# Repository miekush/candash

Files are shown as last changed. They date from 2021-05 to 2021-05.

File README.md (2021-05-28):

# CANDash
STM32 based Controller Area Network Dashboard

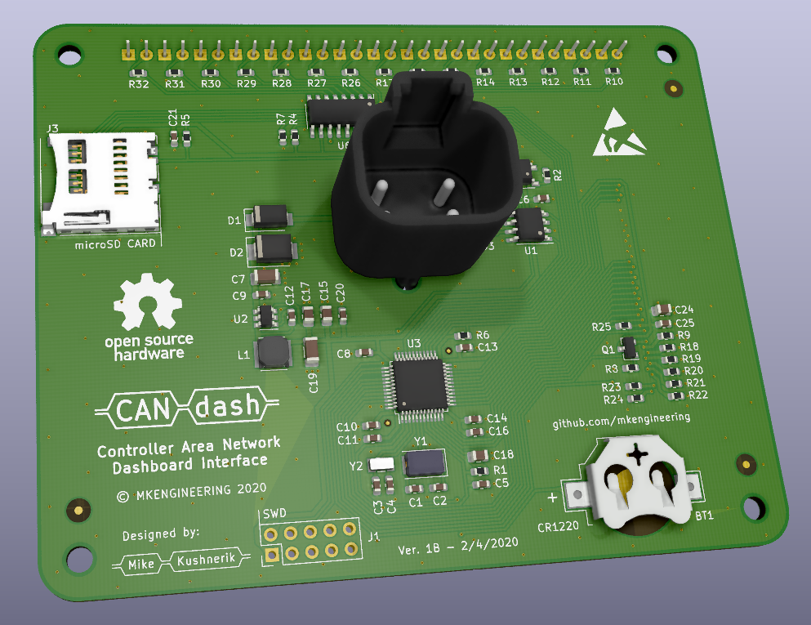
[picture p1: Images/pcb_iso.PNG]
PCB


Designed by Mike Kushnerik (MKE) in KiCad V5

# License

MKE supports the open source hardware community by sharing hardware design files freely on GitHub!

Please support MKE by purchasing products on [Tindie](https://www.tindie.com/stores/mkengineering/)!

Designed by Mike Kushnerik for MKEngineering

Licensed under [Creative Commons Attribution-ShareAlike CC BY-SA 3.0](http://creativecommons.org/licenses/by-sa/3.0/)

All text above must be included in any redistribution!

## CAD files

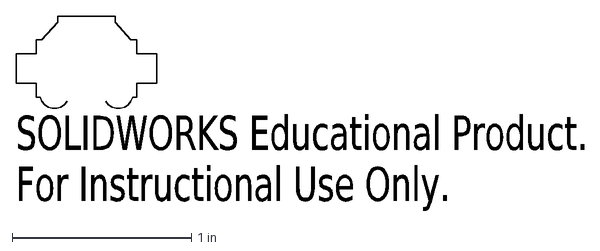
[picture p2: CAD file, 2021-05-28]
3D Models/keystone-PN3000TR_outline.DXF
SOLIDWORKS Educational Product.
For Instructional Use Only.

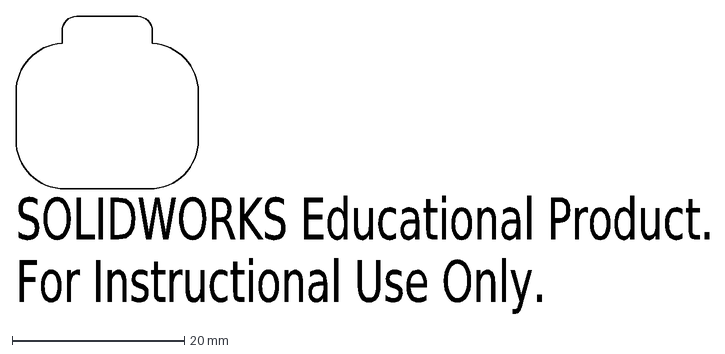
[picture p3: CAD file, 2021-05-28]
3D Models/AT04-4P-BM03_front_porch.DXF
SOLIDWORKS Educational Product.
For Instructional Use Only.

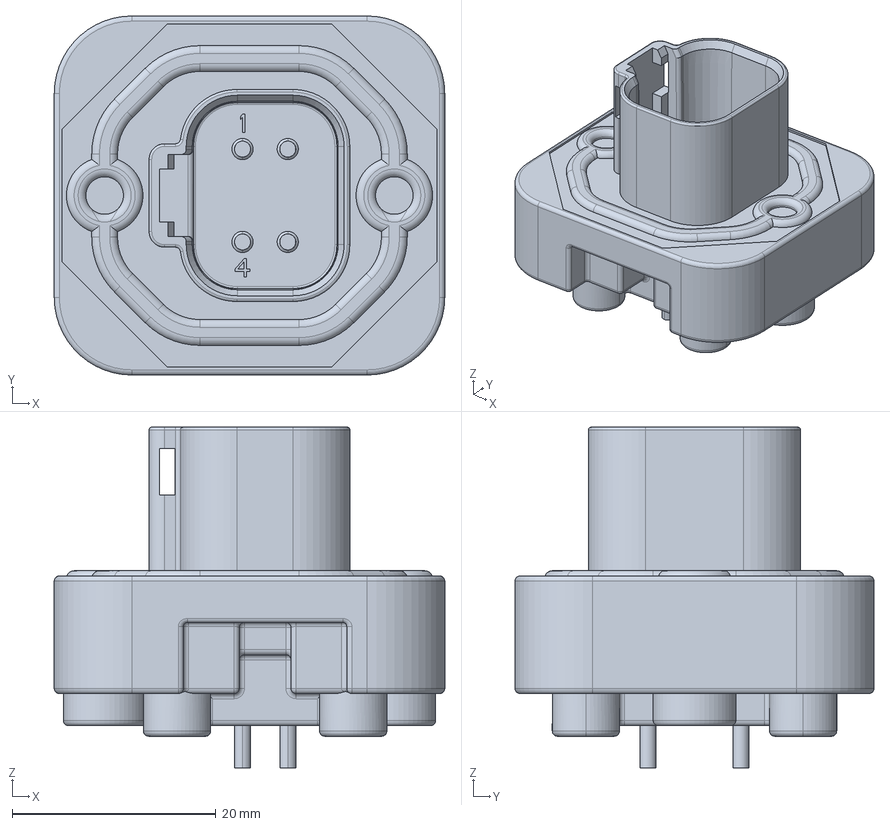
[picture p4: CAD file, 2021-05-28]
3D Models/c-dt15-4p-99-3d.stp
38.4 x 35.3 x 33.5 mm

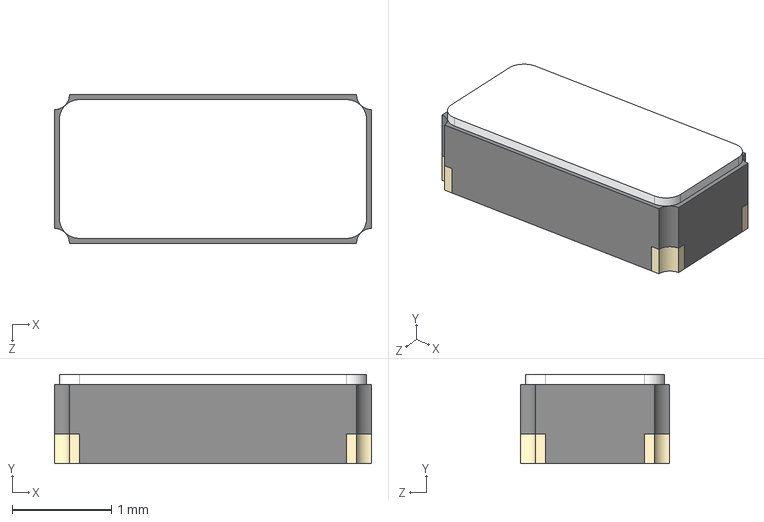
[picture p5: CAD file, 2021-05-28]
3D Models/ABS07-32.768KHZ-1-T.STEP
3.20 x 0.9 x 1.50 mm

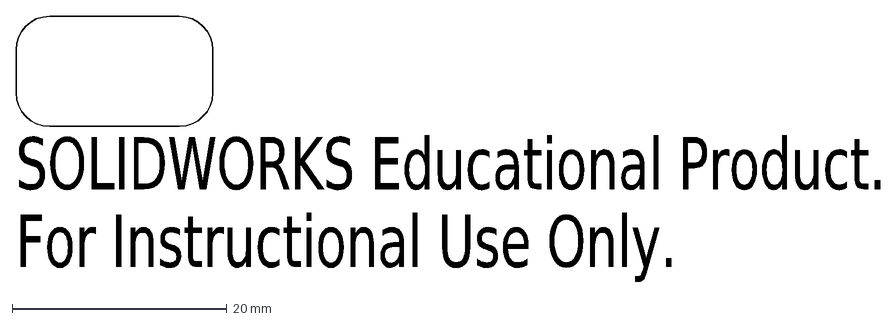
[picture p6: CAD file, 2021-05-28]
3D Models/AT04-4P-BM03_outline.DXF
SOLIDWORKS Educational Product.
For Instructional Use Only.

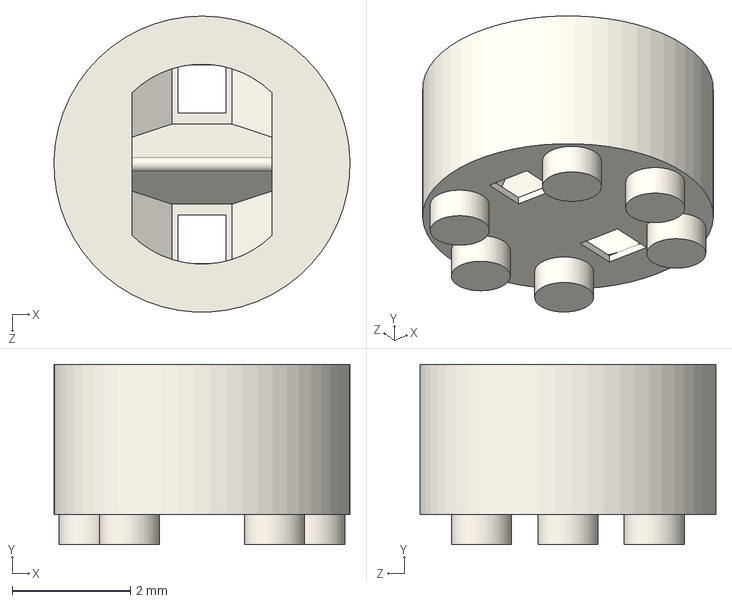
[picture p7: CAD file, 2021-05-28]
3D Models/keystone-PN7351.STEP
5.00 x 3.05 x 5.00 mm

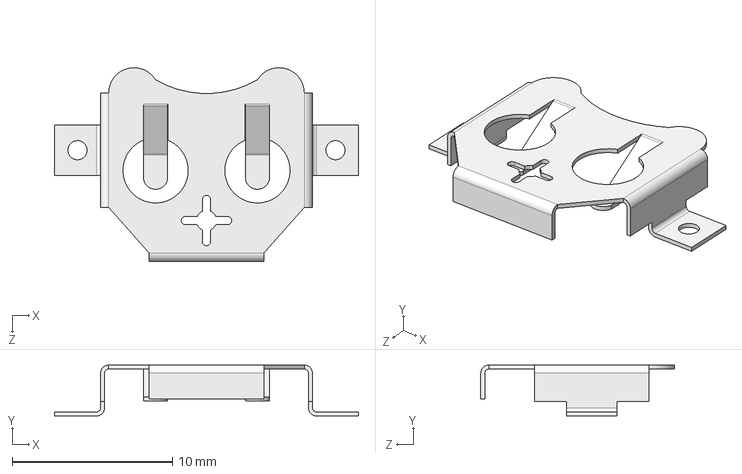
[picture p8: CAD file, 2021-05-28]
3D Models/keystone-PN3000TR.STEP
18.9 x 3.17 x 12.1 mm

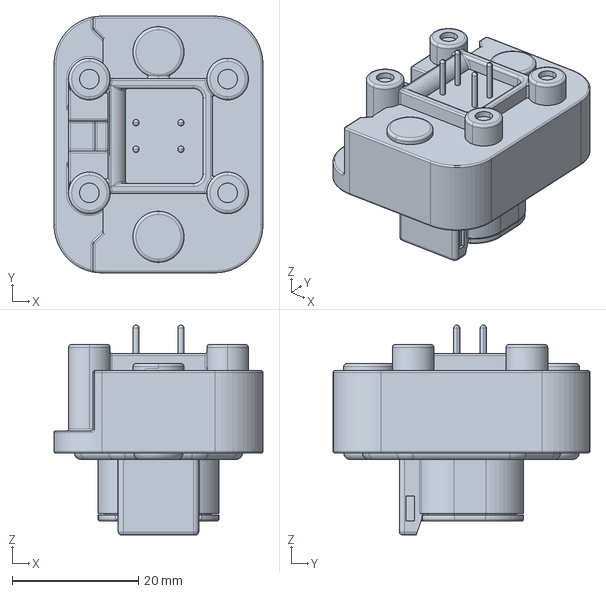
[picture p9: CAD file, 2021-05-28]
3D Models/c-atm15-4p-bm03-3d-c3d.STP
33.1 x 40.7 x 33.2 mm

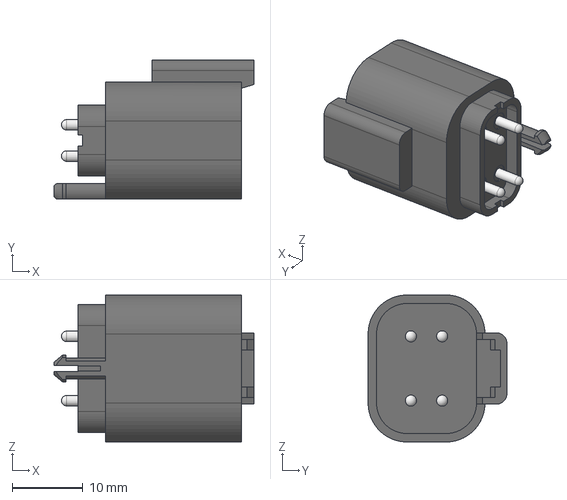
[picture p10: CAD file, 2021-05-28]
3D Models/AT04-4P-BM03.stp
28.3 x 19.6 x 20.8 mm

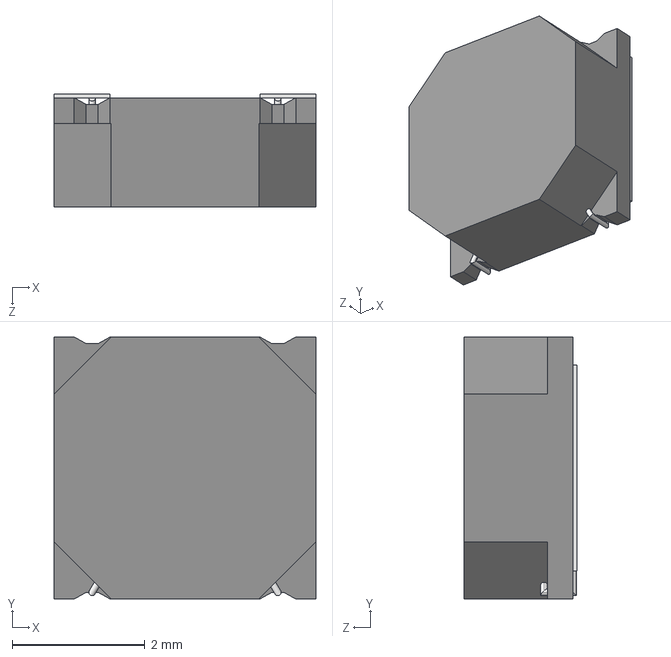
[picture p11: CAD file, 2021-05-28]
3D Models/IFSC1515AHER4R7M01.stp
3.95 x 3.95 x 1.71 mm

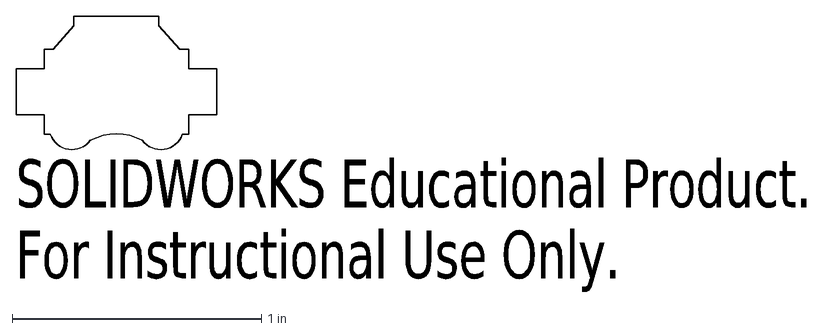
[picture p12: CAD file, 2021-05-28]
3D Models/keystone-PN3000TR_front_porch.DXF
SOLIDWORKS Educational Product.
For Instructional Use Only.

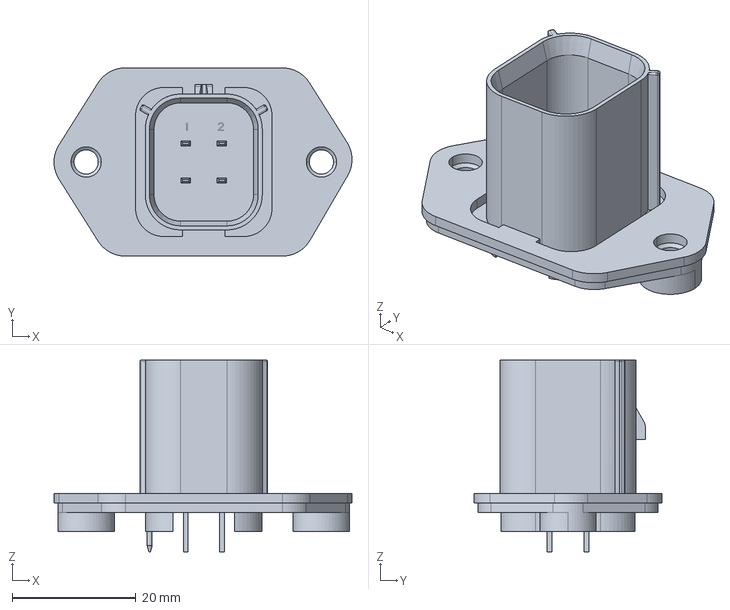
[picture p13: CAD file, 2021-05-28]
3D Models/194280011.stp
48.3 x 30.5 x 31.1 mm

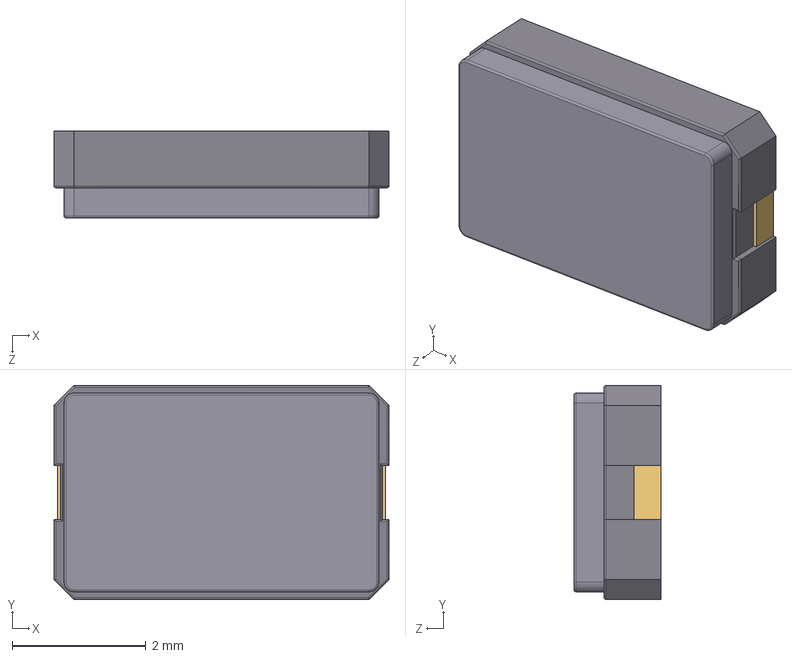
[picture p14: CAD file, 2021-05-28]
3D Models/X50328MSB2GI.STEP
5.00 x 3.20 x 1.30 mm

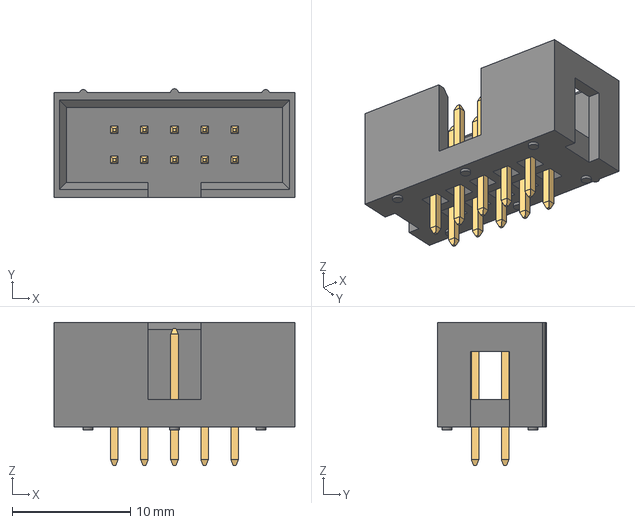
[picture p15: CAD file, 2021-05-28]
3D Models/61201021621 (rev1).stp
20.4 x 9.18 x 12.1 mm
6120xx21621_PIN x 10

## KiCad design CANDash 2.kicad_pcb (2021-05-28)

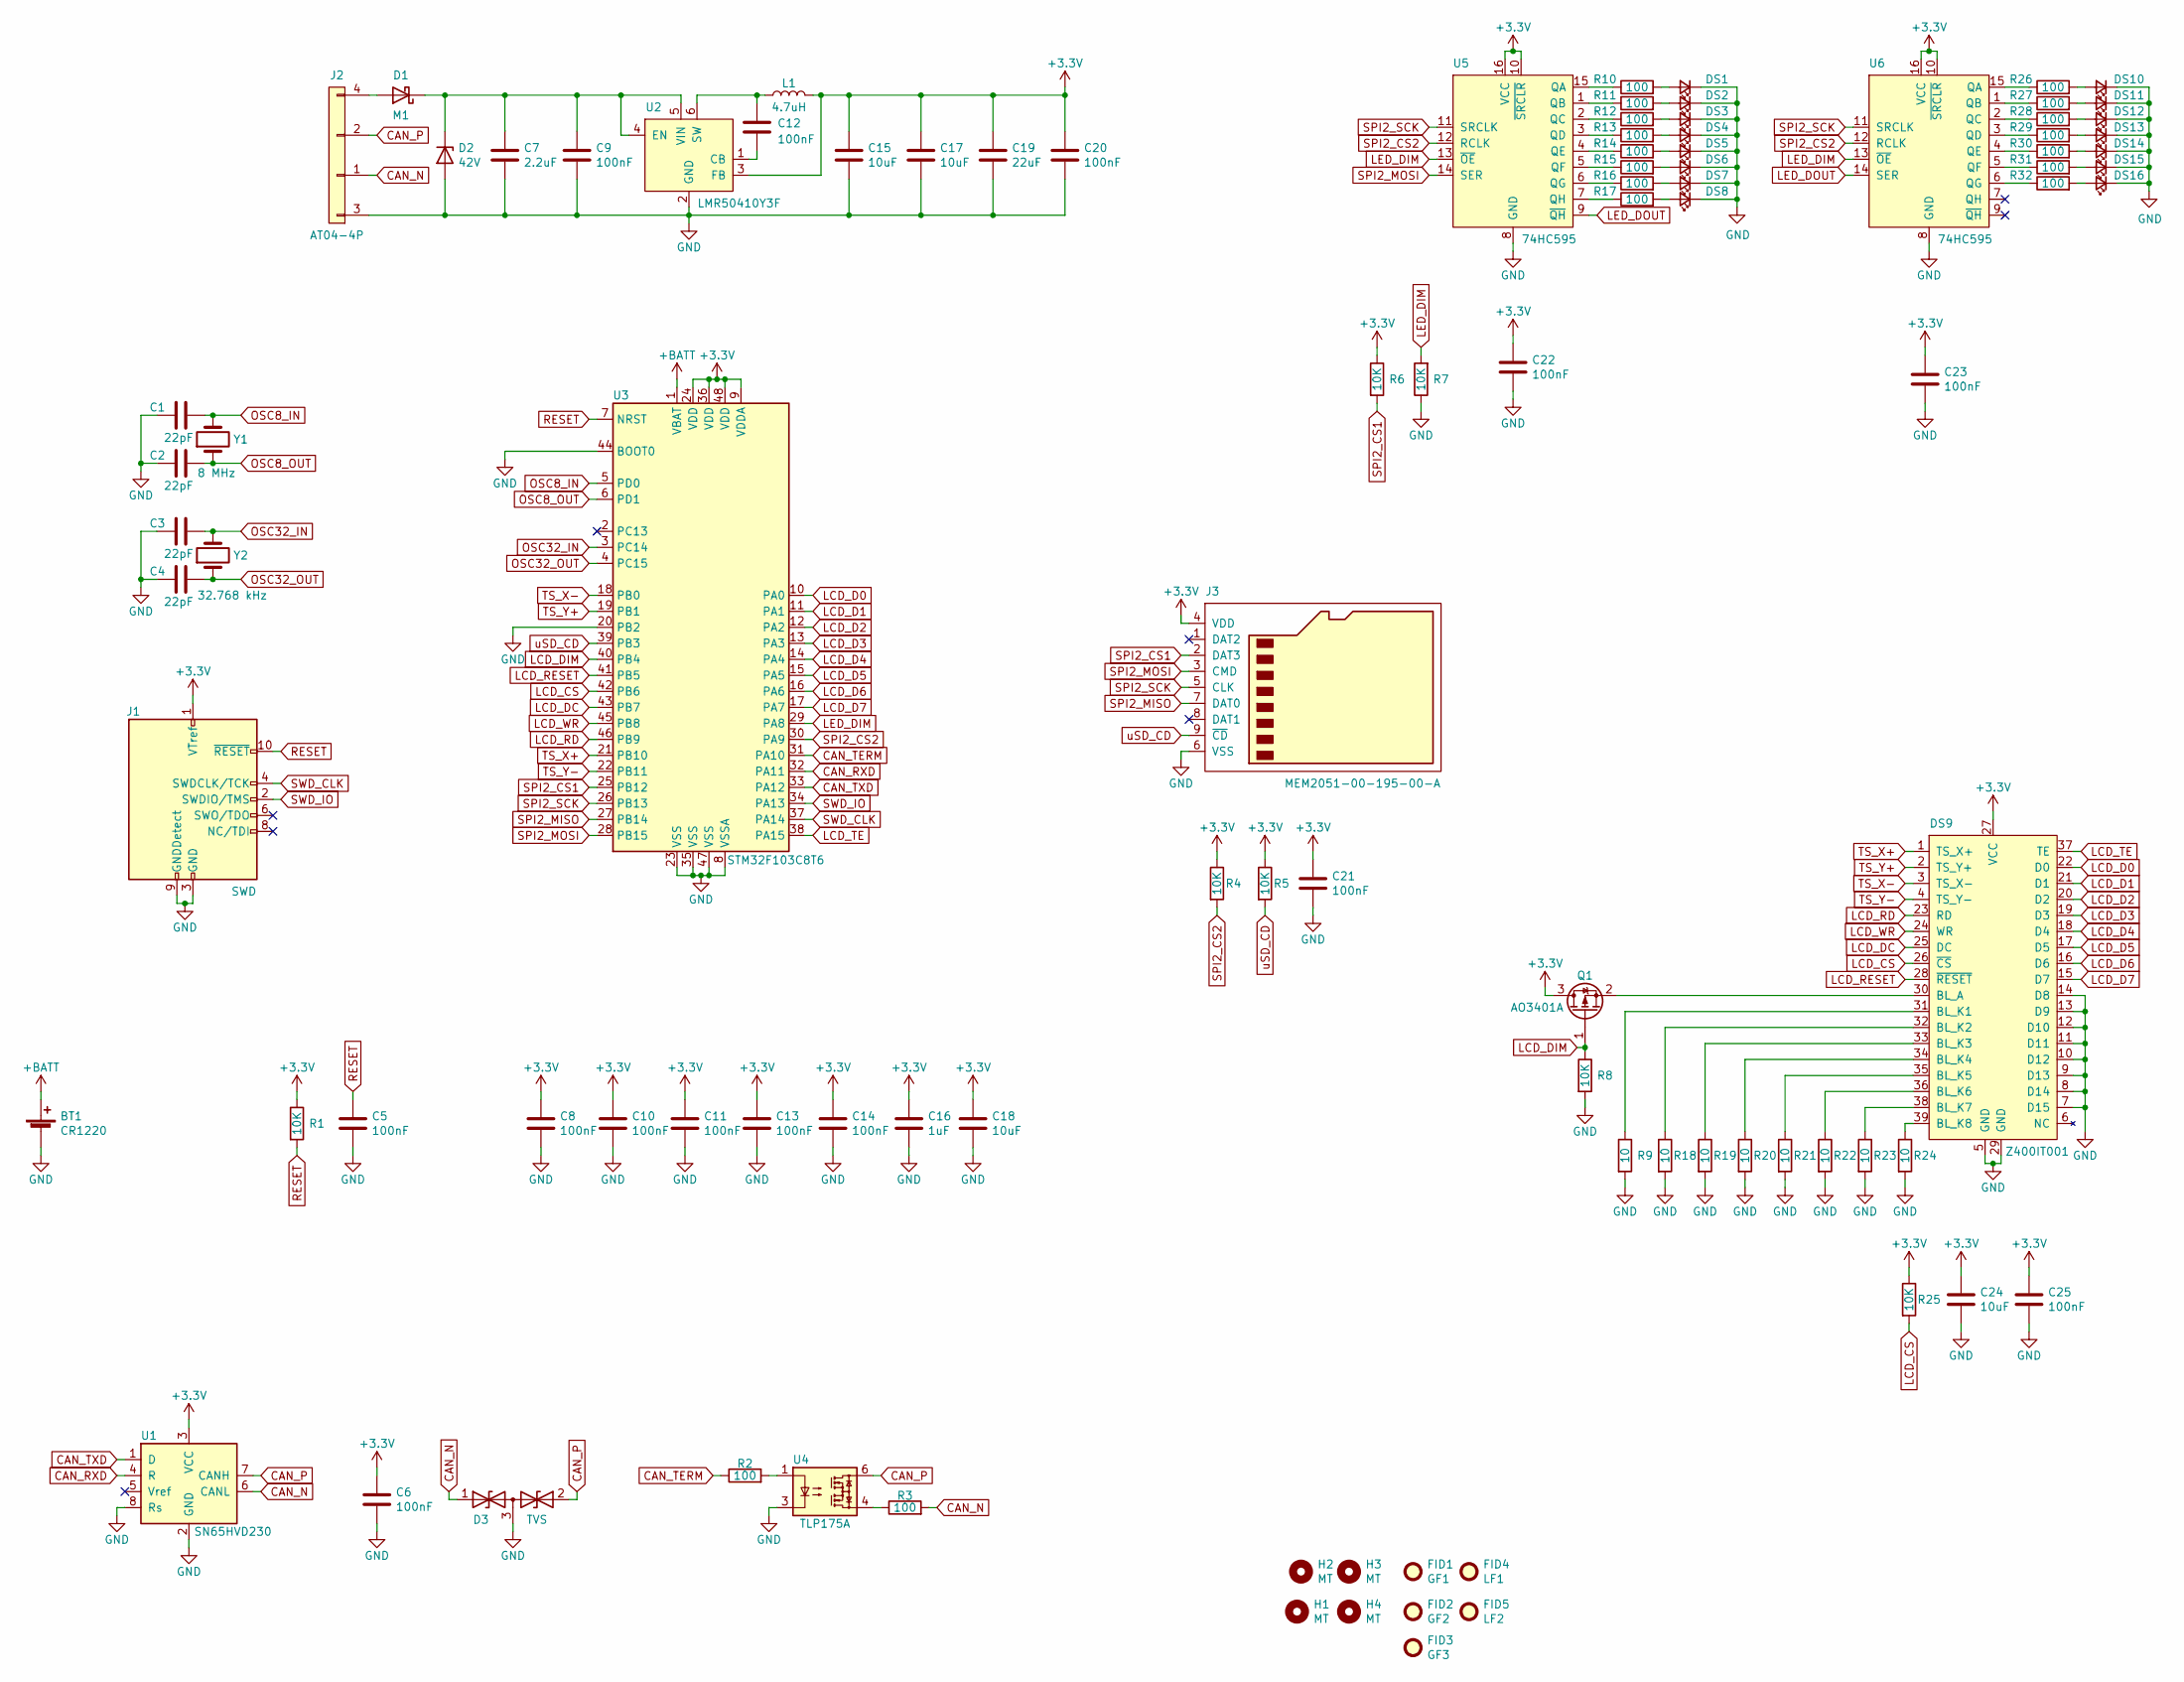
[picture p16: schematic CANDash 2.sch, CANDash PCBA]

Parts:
BT1: CR1220; 3000TR
C1, C2, C3, C4: 22pF; C_0603_1608Metric; LCSC C1653
C5, C6, C8, C9, C10, C11, C12, C13, C14, C20, C21, C22, C23, C25: 100nF; C_0603_1608Metric; LCSC C14663
C7: 2.2uF; C_1206_3216Metric; LCSC C13585
C15, C17, C18, C24: 10uF; C_0805_2012Metric; LCSC C15850
C16: 1uF; C_0603_1608Metric; LCSC C15849
C19: 22uF; C_1206_3216Metric; LCSC C15850
D1: M1; D_SMA
D2: 42V; D_SMB
D3: TVS; SOT-23; LCSC C343993
DS1, DS2, DS3, DS4, DS5, DS6, DS7, DS8, DS10, DS11, DS12, DS13, DS14, DS15, DS16: LED_Small; LED_D3.0mm
DS9: Z400IT001
FID1: GF1; Fiducial_1mm_Mask3mm
FID2: GF2; Fiducial_1mm_Mask3mm
FID3: GF3; Fiducial_1mm_Mask3mm
FID4: LF1; Fiducial_0.5mm_Mask1mm
FID5: LF2; Fiducial_0.5mm_Mask1mm
H1, H2, H3, H4: MT; MountingHole_3.2mm_M3
J1: SWD; PinHeader_2x05_P2.54mm_Vertical
J2: AT04-4P; AT04-4P-BM03
J3: MEM2051-00-195-00-A
L1: 4.7uH; IFSC1515AHER4R7M01
Q1: AO3401A; SOT-23; LCSC C15127
R1, R4, R5, R6, R7, R8, R25: 10K; R_0603_1608Metric; LCSC C25804
R2: 100; R_0603_1608Metric; LCSC C21190
R3, R10, R11, R12, R13, R14, R15, R16, R17, R26, R27, R28, R29, R30, R31, R32: 100; R_0603_1608Metric; LCSC C22775
R9, R18, R19, R20, R21, R22, R23, R24: 10; R_0603_1608Metric; LCSC C22859
U1: SN65HVD230; SOIC-8_3.9x4.9mm_P1.27mm; LCSC C12084
U2: LMR50410Y3F; SOT-23-6
U3: STM32F103C8T6; LQFP-48_7x7mm_P0.5mm; LCSC C8734
U4: TLP175A; MFSOP6-4_4.4x3.6mm_P1.27mm; LCSC C141522
U5, U6: 74HC595; SOIC-16_3.9x9.9mm_P1.27mm
Y1: 8 MHz; Crystal_SMD_5032-2Pin_5.0x3.2mm; LCSC C115962
Y2: 32.768 kHz; Crystal_SMD_3215-2Pin_3.2x1.5mm; LCSC C115962

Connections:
+3V3: C6.1, C8.1, C10.1, C11.1, C13.1, C14.1, C15.1, C16.1, C17.1, C18.1, C19.1, C20.1, C21.1, C22.1, C23.1, C24.1, C25.1, DS9.27 (VCC), J1.1 (VTref), J3.4 (VDD), L1.2, Q1.3 (D), R1.1, R4.1, R5.1, R6.1, R25.1, U1.3 (VCC), U2.3 (FB), U3.9 (VDDA), U3.24 (VDD), U3.36 (VDD), U3.48 (VDD), U5.10 (~SRCLR), U5.16 (VCC), U6.10 (~SRCLR), U6.16 (VCC)
+BATT: BT1.1 (+), U3.1 (VBAT)
CAN_N: D3.1 (A1), J2.1, R3.2, U1.6 (CANL)
CAN_P: D3.2 (A2), J2.2, U1.7 (CANH), U4.6
CAN_RXD: U1.4 (R), U3.32 (PA11)
CAN_TERM: R2.1, U3.31 (PA10)
CAN_TXD: U1.1 (D), U3.33 (PA12)
GND: BT1.2 (-), C1.2, C2.2, C3.2, C4.2, C5.2, C6.2, C7.2, C8.2, C9.2, C10.2, C11.2, C13.2, C14.2, C15.2, C16.2, C17.2, C18.2, C19.2, C20.2, C21.2, C22.2, C23.2, C24.2, C25.2, D2.2 (A), D3.3 (common), DS1.1 (K), DS2.1 (K), DS3.1 (K), DS4.1 (K), DS5.1 (K), DS6.1 (K), DS7.1 (K), DS8.1 (K), DS9.5 (GND), DS9.7 (D15), DS9.8 (D14), DS9.9 (D13), DS9.10 (D12), DS9.11 (D11), DS9.12 (D10), DS9.13 (D9), DS9.14 (D8), DS9.29 (GND), DS10.1 (K), DS11.1 (K), DS12.1 (K), DS13.1 (K), DS14.1 (K), DS15.1 (K), DS16.1 (K), J1.3 (GND), J1.5 (GND), J1.9 (GNDDetect), J2.3, J3.6 (VSS), R7.1, R8.2, R9.2, R18.2, R19.2, R20.2, R21.2, R22.2, R23.2, R24.2, U1.2 (GND), U1.8 (Rs), U2.2 (GND), U3.8 (VSSA), U3.20 (PB2), U3.23 (VSS), U3.35 (VSS), U3.44 (BOOT0), U3.47 (VSS), U4.3, U5.8 (GND), U6.8 (GND)
LCD_CS: DS9.26 (~CS), R25.2, U3.42 (PB6)
LCD_D0: DS9.22 (D0), U3.10 (PA0)
LCD_D1: DS9.21 (D1), U3.11 (PA1)
LCD_D2: DS9.20 (D2), U3.12 (PA2)
LCD_D3: DS9.19 (D3), U3.13 (PA3)
LCD_D4: DS9.18 (D4), U3.14 (PA4)
LCD_D5: DS9.17 (D5), U3.15 (PA5)
LCD_D6: DS9.16 (D6), U3.16 (PA6)
LCD_D7: DS9.15 (D7), U3.17 (PA7)
LCD_DC: DS9.25 (DC), U3.43 (PB7)
LCD_DIM: Q1.1 (G), R8.1, U3.40 (PB4)
LCD_RD: DS9.23 (RD), U3.46 (PB9)
LCD_RESET: DS9.28 (~RESET), U3.41 (PB5)
LCD_TE: DS9.37 (TE), U3.38 (PA15)
LCD_WR: DS9.24 (WR), U3.45 (PB8)
LED_DIM: R7.2, U3.29 (PA8), U5.13 (~OE), U6.13 (~OE)
LED_DOUT: U5.9 (~QH), U6.14 (SER)
unnamed: C7.1, C9.1, D1.1 (K), D2.1 (K), U2.4 (EN), U2.5 (VIN)
unnamed: C12.1, L1.1, U2.6 (SW)
unnamed: C12.2, U2.1 (CB)
unnamed: D1.2 (A), J2.4
unnamed: DS1.2 (A), R10.2
unnamed: DS2.2 (A), R11.2
unnamed: DS3.2 (A), R12.2
unnamed: DS4.2 (A), R13.2
unnamed: DS5.2 (A), R14.2
unnamed: DS6.2 (A), R15.2
unnamed: DS7.2 (A), R16.2
unnamed: DS8.2 (A), R17.2
unnamed: DS9.30 (BL_A), Q1.2 (S)
unnamed: DS9.31 (BL_K1), R9.1
unnamed: DS9.32 (BL_K2), R18.1
unnamed: DS9.33 (BL_K3), R19.1
unnamed: DS9.34 (BL_K4), R20.1
unnamed: DS9.35 (BL_K5), R21.1
unnamed: DS9.36 (BL_K6), R22.1
unnamed: DS9.38 (BL_K7), R23.1
unnamed: DS9.39 (BL_K8), R24.1
unnamed: DS10.2 (A), R26.2
unnamed: DS11.2 (A), R27.2
unnamed: DS12.2 (A), R28.2
unnamed: DS13.2 (A), R29.2
unnamed: DS14.2 (A), R30.2
unnamed: DS15.2 (A), R31.2
unnamed: DS16.2 (A), R32.2
unnamed: R2.2, U4.1
unnamed: R3.1, U4.4
unnamed: R10.1, U5.15 (QA)
unnamed: R11.1, U5.1 (QB)
unnamed: R12.1, U5.2 (QC)
unnamed: R13.1, U5.3 (QD)
unnamed: R14.1, U5.4 (QE)
unnamed: R15.1, U5.5 (QF)
unnamed: R16.1, U5.6 (QG)
unnamed: R17.1, U5.7 (QH)
unnamed: R26.1, U6.15 (QA)
unnamed: R27.1, U6.1 (QB)
unnamed: R28.1, U6.2 (QC)
unnamed: R29.1, U6.3 (QD)
unnamed: R30.1, U6.4 (QE)
unnamed: R31.1, U6.5 (QF)
unnamed: R32.1, U6.6 (QG)
OSC8_IN: C1.1, U3.5 (PD0), Y1.2
OSC8_OUT: C2.1, U3.6 (PD1), Y1.1
OSC32_IN: C3.1, U3.3 (PC14), Y2.2
OSC32_OUT: C4.1, U3.4 (PC15), Y2.1
RESET: C5.1, J1.10 (~RESET~), R1.2, U3.7 (NRST)
SPI2_CS1: J3.2 (DAT3), R6.2, U3.25 (PB12)
SPI2_CS2: R4.2, U3.30 (PA9), U5.12 (RCLK), U6.12 (RCLK)
SPI2_MISO: J3.7 (DAT0), U3.27 (PB14)
SPI2_MOSI: J3.3 (CMD), U3.28 (PB15), U5.14 (SER)
SPI2_SCK: J3.5 (CLK), U3.26 (PB13), U5.11 (SRCLK), U6.11 (SRCLK)
SWD_CLK: J1.4 (SWDCLK/TCK), U3.37 (PA14)
SWD_IO: J1.2 (SWDIO/TMS), U3.34 (PA13)
TS_X+: DS9.1 (TS_X+), U3.21 (PB10)
TS_X-: DS9.3 (TS_X-), U3.18 (PB0)
TS_Y+: DS9.2 (TS_Y+), U3.19 (PB1)
TS_Y-: DS9.4 (TS_Y-), U3.22 (PB11)
uSD_CD: J3.9 (~CD), R5.2, U3.39 (PB3)

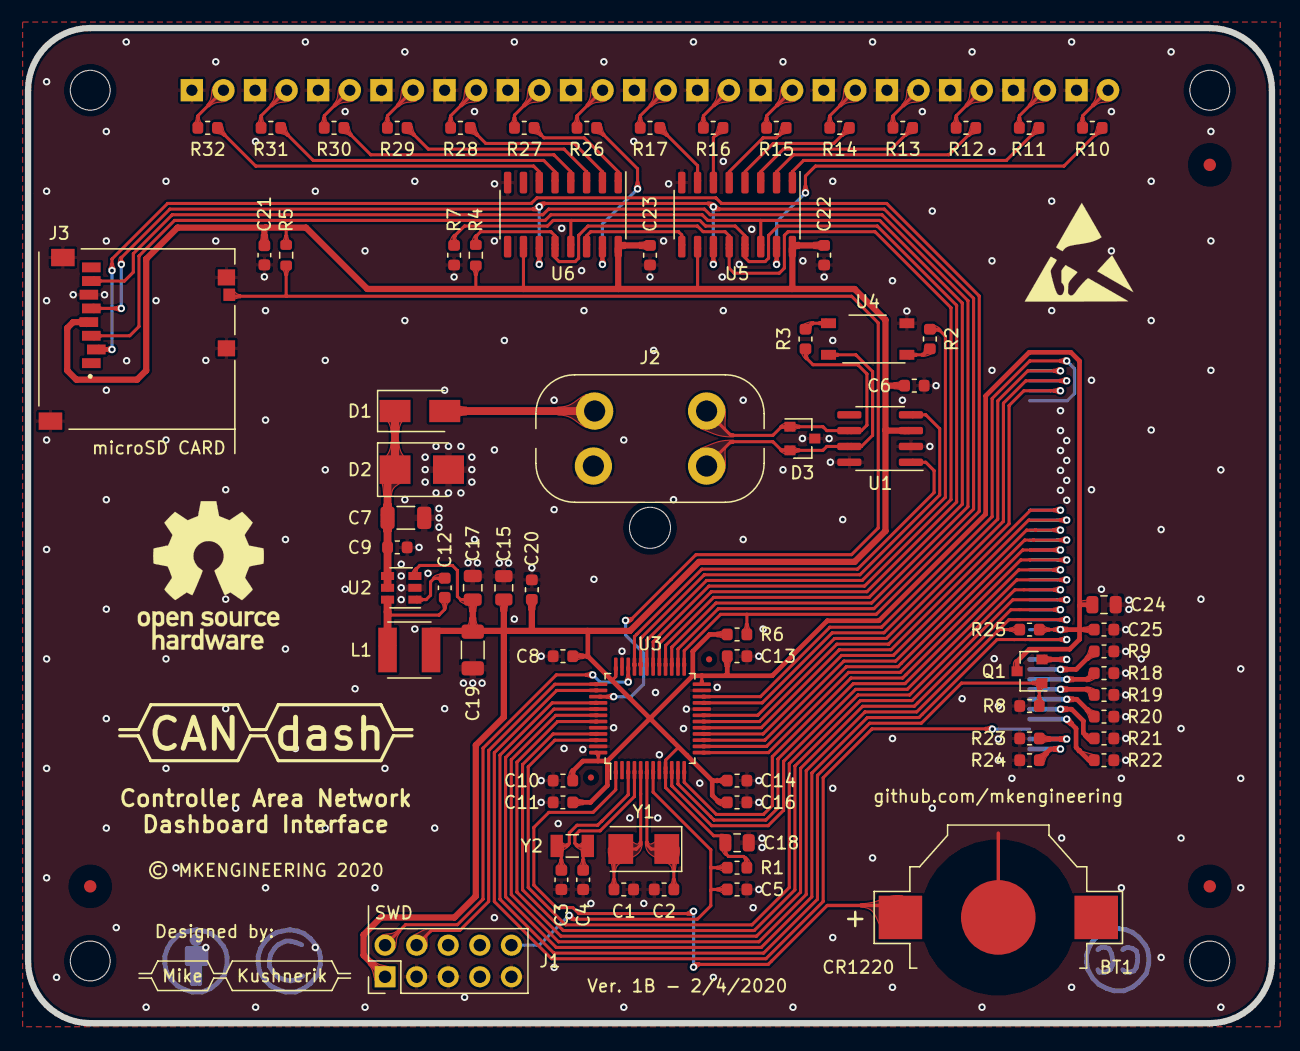
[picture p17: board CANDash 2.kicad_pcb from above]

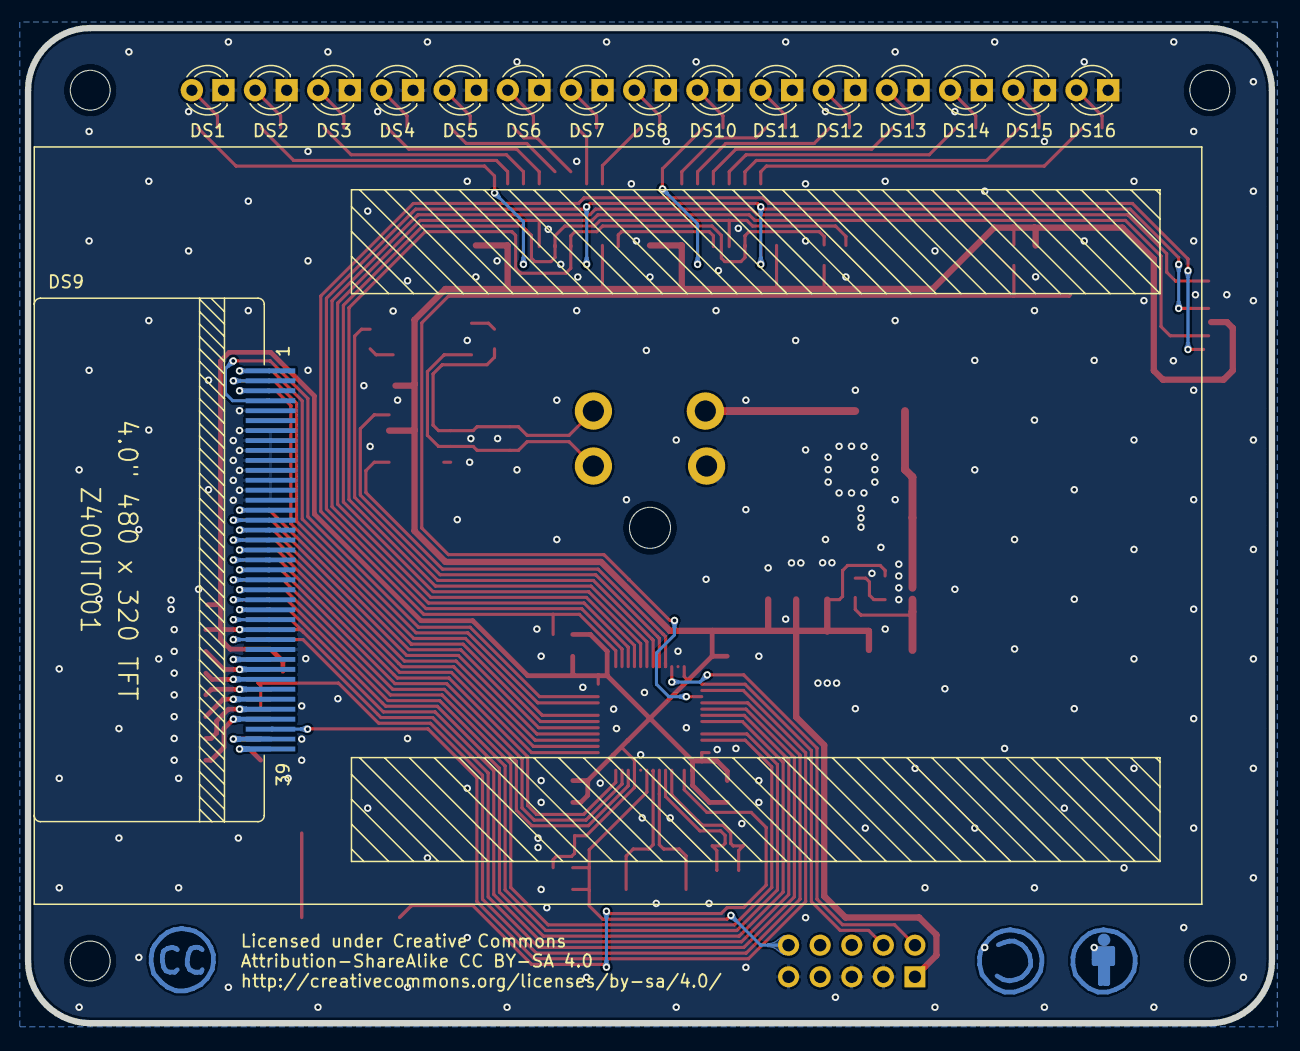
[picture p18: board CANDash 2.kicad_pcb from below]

Board: 2 copper layers, 100.0 x 80.0 mm, 99 parts (16 on the bottom side), 87 nets.

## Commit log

2019-12-26 Add 12-24-2019 REV A Gerber and Drill Files
    Latest Gerber and Drill Files for the CANDash main PCB.
    Fixes:
    -Added 150K pull ups onto the LP55231 INT and EN pins
    -Added 150K pull down onto the LP55231 TRIG pins
    -Added 100K pull up to uSD card CS pin
    -Replaced VHN5019 driver IC with two, MJD122 NPN Darlington Transistors
    -Added silkscreen logos and other designator marks and labels
    -Rebuilt teardrops
    *Gerbers and Drill Files sent to JLC PCB for Prototype Fabrication*
2019-12-26 Delete CANDash_Drill_12_24_19.Cam
    -moved to PCB Files
2019-12-26 Delete CANDash_Gerber_12_24_19.Cam
    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
2019-12-26 Create PCB Fabrication Files
2019-12-26 Add 12-24-2019 REV 1A Gerber and Drill Files
    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
2019-12-26 Add Rev. 1A PCB CAD Photos
    CAD Renderings of the Rev. 1A CANDash PCB
2019-12-26 Add Gerber Photos
    Gerber Photos of the Rev. 1A CANDash PCB
2021-05-28 Initial Upload
    [194280011.stp, 61201021621 (rev1).stp, ABS07-32.768KHZ-1-T.STEP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]

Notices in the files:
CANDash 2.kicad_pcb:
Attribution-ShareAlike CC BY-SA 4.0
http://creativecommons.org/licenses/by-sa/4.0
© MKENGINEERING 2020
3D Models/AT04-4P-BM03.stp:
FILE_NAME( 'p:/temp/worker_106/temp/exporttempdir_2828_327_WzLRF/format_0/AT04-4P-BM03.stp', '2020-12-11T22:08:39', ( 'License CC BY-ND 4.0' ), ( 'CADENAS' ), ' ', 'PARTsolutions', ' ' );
